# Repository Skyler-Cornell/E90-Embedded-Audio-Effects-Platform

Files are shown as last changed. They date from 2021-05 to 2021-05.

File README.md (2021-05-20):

# E90: Low Cost Embedded DSP Development Platform

The platform is designed for the development of DSP algorithms and provides the hardware and software infrastructure to get started writing programs manipulating real time audio signals in the C programming language. The board manages the analog audio input and output circuits, microcontroller peripherals, and the data flow, allowing a programmer to focus their efforts on designing DSP. The board was also designed wih musicians in mind, and can act as a programmable real time effects unit that players can plug their instruments into and run pre-compiled effects. An eventual goal of the project is to curate a growing library of pre-compiled firmware written by a community of developers that anyone can download and easily upload to the board to try out with their instruments. 

The board supports stereo 24bit audio at 48kHz sampling and implements a highly optimized DMA audio stream scheme. Refer to the Getting Started Manual pdf to ... get started using the platform.

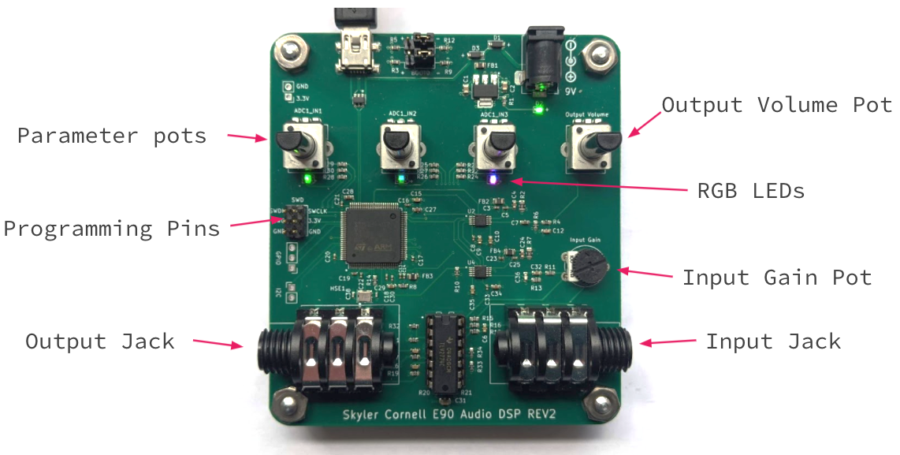
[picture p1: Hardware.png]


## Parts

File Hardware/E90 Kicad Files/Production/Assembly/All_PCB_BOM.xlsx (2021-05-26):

Item # | *Designator | *Qty | Manufacturer | *Mfg Part # | Description / Value | *Package/Footprint | Type | LCSC Part Number
1 | C1,C2,C31 | 3 | Samsung Electro-Mechanics | CL21A106KOQNNNE | 10uF ±10% 16V 0805 Multilayer Ceramic Capacitors | 0805 | SMD | C1713
2 | C12 | 1 | Walsin Tech Corp | 0603B272K101CT | 2.7nF ±10% 100V 0603 Multilayer Ceramic Capacitors | 0603 | SMD | C302023
3 | C13,C17,C19,C21,C22,C16,C18,C20,C3,C8,C33,C23,C30,C5,C25 | 15 | Walsin Tech Corp | 0402X104K160CT | 100nF ±10% 16V 0402 Multilayer Ceramic Capacitors | 0402 | SMD | C301997
4 | C14 | 1 | CCTC | TCC0402X7R103K500AT | 10nF ±10% 50V 0402 Multilayer Ceramic Capacitors | 0402 | SMD | C688874
5 | C15,C6,C11,C26,C9,C10,C35 | 7 | Murata Electronics | GRM188R61A106ME69D | 10uF ±20% 10V 0603 Multilayer Ceramic Capacitors | 0603 | SMD | C90053
6 | C27,C28 | 2 | YAGEO | CC0603KRX5R8BB225 | 2.2uF ±10% 25V 0603 Multilayer Ceramic Capacitors | 0603 | SMD | C309478
7 | C29,C34,C32 | 3 | Samsung Electro-Mechanics | CL10A105KP8NNNC | 1uF ±10% 10V 0603 Multilayer Ceramic Capacitors | 0603 | SMD | C26413
8 | C36 | 1 | YAGEO | CC0603FRNPO9BN181 | 180pF ±1% 50V 0603 Multilayer Ceramic Capacitors | 0603 | SMD | C527047
9 | C38,C39 | 2 | Murata Electronics | GCM1555C1H120JA16D | 12pF ±5% 50V 0402 Multilayer Ceramic Capacitors | 0402 | SMD | C126495
10 | C4,C24 | 2 | Samsung Electro-Mechanics | CL10A475KP8NNNC | 4.7uF ±10% 10V 0603 Multilayer Ceramic Capacitors | 0603 | SMD | C1705
11 | C7 | 1 | Walsin Tech Corp | 0603X335K100CT | 3.3uF ±10% 10V 0603 Multilayer Ceramic Capacitors | 0603 | SMD | C237213
12 | D1,D3 | 2 | AnBon | B5819W | SOD-123 Schottky Diodes | SOD-123 | SMD | C541627
13 | D2 | 1 | TOGIALED | TJ-S1608CY6T5ALC2G-A5 | Green 0603 Light Emitting Diodes (LED) | 0603 | SMD | C440518
14 | D5,D4,D6 | 3 | Everlight Elec | 19-237/R6GHBHC-A01/2T | RGB SMD Light Emitting Diodes (LED) | SMD | SMD | C60105
15 | FB2,FB4 | 2 | Sunlord | GZ2012D601TF | 600Ω @ 100MHz 0805 Ferrite Beads | 0805 | SMD | C1017
16 | FB3,FB1 | 2 | Sunlord | GZ2012D101TF | 100Ω @ 100MHz 0805 Ferrite Beads | 0805 | SMD | C1015
17 | HSE1 | 1 | Seiko Epson | X1E000021037500 | 16MHz ±10ppm 9pF 60Ω SMD-3225_4P SMD Crystal Resonators | SMD-3225_4P | SMD | C89379
18 | R1 | 1 | UNI-ROYAL(Uniroyal Elec) | 0603WAJ0222T5E | 2.2kΩ ±5% 0.1W 0603 Chip Resistor | 0603 | SMD | C25992
19 | R11,R13 | 2 | UNI-ROYAL(Uniroyal Elec) | 0603WAF5101T5E | 5.1kΩ ±1% 0.1W 0603 Chip Resistor | 0603 | SMD | C23186
20 | R14 | 1 | TyoHM | RMC06031001%N | 100Ω ±1% 0.1W 0603 Chip Resistor | 0603 | SMD | C269700
21 | R16,R15,R18,R17,R19,R12,R5,R9,R3,R20,R21,R10,R33,R34,R31,R32,R6 | 17 | UNI-ROYAL(Uniroyal Elec) | 0603WAJ0104T5E | 100kΩ ±5% 0.1W 0603 Chip Resistor | 0603 | SMD | C15458
22 | R2,R7 | 2 | UNI-ROYAL(Uniroyal Elec) | 0805W8J010JT5E | 1Ω ±5% 0.125W 0805 Chip Resistor | 0805 | SMD | C25288
23 | R27,R26,R25,R24,R23,R22,R28,R29,R30 | 9 | UNI-ROYAL(Uniroyal Elec) | 0603WAD1001T5E | 1kΩ ±0.5% 0.1W 0603 Chip Resistor | 0603 | SMD | C51218
24 | R4 | 1 | FH(Guangdong Fenghua Advanced Tech) | RS-03K4700FT | 470Ω ±1% 0.1W 0603 Chip Resistor | 0603 | SMD | C116694
25 | R8 | 1 | FH(Guangdong Fenghua Advanced Tech) | RS-03K47R0FT | 47Ω ±1% 0.1W 0603 Chip Resistor | 0603 | SMD | C140087
26 | U1 | 1 | Advanced Monolithic Systems | AMS1117-3.3 | Fixed 15V 3.3V 1.3V @ 800mA SOT-223 Dropout Regulators(LDO) | SOT-223 | SMD | C6186
27 | U2 | 1 | Cirrus Logic | CS4344-CZZR | TSSOP-10 Digital To Analog Converters (DACs) | TSSOP-10 | SMD | C8952
28 | U4 | 1 | Cirrus Logic | CS5343-CZZR | TSSOP-10 Analog To Digital Converters (ADCs) | TSSOP-10 | SMD | C323607
29 | U5 | 1 | STMicroelectronics | STM32F407VGT6 | LQFP-100 STM32 Microcontroller | LQFP-100_14x14x05P | SMD | C12345
30 | U6 | 1 | STMicroelectronics | USBLC6-2SC6 | DIODES - ESD SOT-23-6 | SOT-23-6 | SMD | C7519

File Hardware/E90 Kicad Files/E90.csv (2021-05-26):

Reference | Quantity | Value | Footprint | Datasheet | LCSC
C1 C2 C31 | 3 | 10uF | Capacitor_SMD:C_0805_2012Metric | ~ | C15850
C12 | 1 | 2.7nF | Capacitor_SMD:C_0603_1608Metric | ~ | C1609
C13 C17 C19 C21 C22 C16 C18 C20 C3 C8 C33 C23 | 12 | 100nf | Capacitor_SMD:C_0402_1005Metric | ~ | C1525
C14 | 1 | 10nF | Capacitor_SMD:C_0402_1005Metric | ~ | C15195
C15 C6 C11 C26 C9 C10 C35 | 7 | 10uF | Capacitor_SMD:C_0603_1608Metric | ~ | C19702
C27 C28 | 2 | 2.2uF | Capacitor_SMD:C_0603_1608Metric | ~ | C23630
C29 C34 C32 | 3 | 1uF | Capacitor_SMD:C_0603_1608Metric | ~ | C15849
C30 C5 C25 | 3 | 100nF | Capacitor_SMD:C_0402_1005Metric | ~ | C1525
C36 | 1 | 180pF | Capacitor_SMD:C_0603_1608Metric | ~ | C18437
C38 C39 | 2 | 12pF | Capacitor_SMD:C_0402_1005Metric | ~ | C1547
C4 C24 | 2 | 4.7uF | Capacitor_SMD:C_0603_1608Metric | ~ | C19666
C7 | 1 | 3.3uF | Capacitor_SMD:C_0603_1608Metric | ~ | C51412
D1 D3 | 2 | B5819W | Diode_SMD:D_SOD-123 | ~ | C8598
D2 | 1 | LED_Green | LED_SMD:LED_0603_1608Metric | ~ | C72043
D5 D4 D6 | 3 | LED_RGBA | LED_SMD:19-237-R6GHBHC-A01-2T | ~ | C60105
FB2 FB4 | 2 | 600 @100 MHz | Inductor_SMD:L_0805_2012Metric | ~ | C1017
FB3 FB1 | 2 | 100 @100 MHz | Inductor_SMD:L_0805_2012Metric | ~ | C1015
HSE1 | 1 | 16MHz | Crystal:Crystal_SMD_3225-4Pin_3.2x2.5mm | ~ | C13738
R1 | 1 | 2k2 | Resistor_SMD:R_0603_1608Metric | ~ | C4190
R11 R13 | 2 | 5.1K | Resistor_SMD:R_0603_1608Metric | ~ | C23186
R14 | 1 | 100 | Resistor_SMD:R_0603_1608Metric | ~ | C22775
R16 R15 R18 R17 R19 R12 R5 R9 R3 R20 R21 R10 R33 R34 R31 R32, R6 | 17 | 10k | Resistor_SMD:R_0603_1608Metric | ~ | C25804
R2 R7 | 2 | 1 | Resistor_SMD:R_0805_2012Metric | ~ | C25271
R27 R26 R25 R24 R23 R22 R28 R29 R30 | 9 | 1k | Resistor_SMD:R_0603_1608Metric | ~ | C21190
R4 | 1 | 470 | Resistor_SMD:R_0603_1608Metric | ~ | C23179
R8 | 1 | 47 | Resistor_SMD:R_0603_1608Metric | ~ | C23182
U1 | 1 | AMS1117-3.3 | Package_TO_SOT_SMD:SOT-223-3_TabPin2 | http://www.advanced-monolithic.com/pdf/ds1117.pdf | C6186
U2 | 1 | CS4344_CZZ | Package_TSSOP_SMD:SOP50P490X110-10N
U4 | 1 | CS5343_CZZ | Package_TSSOP_SMD:SOP50P490X110-10N
U5 | 1 | STM32F407VGT60 | Package_QFP:LQFP-100_14x14mm_P0.5mm | http://www.st.com/st-web-ui/static/active/en/resource/technical/document/datasheet/DM00037051.pdf | C919362
U6 | 1 | USBLC6-2SC6 | Package_TO_SOT_SMD:SOT-23-6 | http://www2.st.com/resource/en/datasheet/CD00050750.pdf | C7519

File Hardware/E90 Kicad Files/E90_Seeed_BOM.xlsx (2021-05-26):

Designator | Qty | Manufacturer Part Number or Seeed SKU | Link | Manufactorer | Footprint | Value
C1 C2 C31 | 3 | 302010158 | https://statics3.seeedstudio.com/fusion/opl/datasheet/302010158.pdf | YAGEO | 0805 | 10uF
C12 | 1 | 0603B272K500NT | https://file.elecfans.com/web1/M00/B0/EC/pIYBAF3vREiAa21yAA-X9Qix-h8261.pdf?filename=0603B272K500NT_FH.pdf | FH | 0603 | 2.7nF
C13 C17 C19 C21 C22 C16 C18 C20 C3 C8 C33 C23 | 12 | 302010024 | https://statics3.seeedstudio.com/fusion/opl/datasheet/302010024.pdf | YAGEO | 0402 | 100nf
C14 | 1 | 302010006 | https://statics3.seeedstudio.com/fusion/opl/datasheet/302010006.pdf | YAGEO | 0402 | 10nF
C15 C6 C11 C26 C9 C10 C35 | 7 | 302010103 | https://statics3.seeedstudio.com/fusion/opl/datasheet/302010103.pdf | YAGEO | 0603 | 10uF
C27 C28 | 2 | 302010054 | https://statics3.seeedstudio.com/fusion/opl/datasheet/302010054.pdf | YAGEO | 0603 | 2.2uF
C29 C34 C32 | 3 | 302010139 | https://statics3.seeedstudio.com/fusion/opl/datasheet/302010139.pdf | YAGEO | 0603 | 1uF
C30 C5 C25 | 3 | 302010024 | https://statics3.seeedstudio.com/fusion/opl/datasheet/302010024.pdf | YAGEO | 0402 | 100nF
C36 | 1 | 0603B181K500NT | https://file.elecfans.com/web1/M00/7D/4D/o4YBAFwKKSOANZPCAA-X9Qix-h8480.pdf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 | FH | 0603 | 180pF
C38 C39 | 2 | 302010049 | https://statics3.seeedstudio.com/fusion/opl/datasheet/302010049.pdf | YAGEO | 0402 | 12pF
C4 C24 | 2 | 302010111 | https://statics3.seeedstudio.com/fusion/opl/datasheet/302010111.pdf | YAGEO | 0603 | 4.7uF
C7 | 1 | CL10A335KP8NNNC | https://file.elecfans.com/web1/M00/5C/4C/o4YBAFt04FWAbe4gAAKwH_HJHDI122.pdf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 | SAMSUNG | 0603 | 3.3uF
R1 | 1 | 301010124 | https://statics3.seeedstudio.com/fusion/opl/datasheet/301010124.pdf | YAGEO | 0603 | 2k2
R11 R13 | 2 | 301010227 | https://statics3.seeedstudio.com/fusion/opl/datasheet/301010227.pdf | YAGEO | 0603 | 5.1K
R14 | 1 | 301010090 | https://statics3.seeedstudio.com/fusion/opl/datasheet/301010090.pdf | YAGEO | 0603 | 100
R16 R15 R18 R17 R19 R12 R5 R9 R3 R20 R21 R10 R33 R34 R31 R32 | 16 | 301010293 | https://statics3.seeedstudio.com/fusion/opl/datasheet/301010293.pdf | YAGEO | 0603 | 10k
R2 R7 | 2 | 0805W8F100KT5E | https://file.elecfans.com/web1/M00/61/0C/o4YBAFt-dwWACUP4AAh1Wgzv73Y460.pdf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 | Uniohm | 0805 | 1
R27 R26 R25 R24 R23 R22 R28 R29 R30 | 9 | 301010291 | https://statics3.seeedstudio.com/fusion/opl/datasheet/301010291.pdf | YAGEO | 0603 | 1k
R4 | 1 | 301010088 | https://statics3.seeedstudio.com/fusion/opl/datasheet/301010088.pdf | YAGEO | 0603 | 470
R6 | 1 | 301010293 | https://statics3.seeedstudio.com/fusion/opl/datasheet/301010293.pdf | YAGEO | 0603 | 10K
R8 | 1 | 301010091 | https://statics3.seeedstudio.com/fusion/opl/datasheet/301010091.pdf | YAGEO | 0603 | 47
U1 | 1 | AMS1117-3.3 | https://file.elecfans.com/web1/M00/B9/0E/pIYBAF57-siAbfa2AAFzrzYJ30Q057.pdf?filename=AMS1117_AMS.pdf | AMS(美国) | SOT-223-3 | AMS1117-3.3
U2 | 1 | CS4344-CZZR | https://d3uzseaevmutz1.cloudfront.net/pubs/proDatasheet/CS4344-45-48_F2.pdf | Cirrus Logic | 10LD TSSOP | CS4344_CZZ
U5 | 1 | STM32F407VGT6 | https://www.mouser.com/datasheet/2/389/dm00037051-1797298.pdf | ST | LQPF-100 | STM32F407VGT60
U6 | 1 | USBLC6-2P6 | https://file.elecfans.com/web1/M00/7F/9E/pIYBAFwjN3uAIFePAANr_4V7kNY752.pdf?filename=USBLC6-2_ST.pdf | ST | SOT-23-6 | USBLC6-2SC6
D1 D3 | 2 | B5819W | https://file.elecfans.com/web1/M00/8A/32/pIYBAFyLiveAInCMAAthN3CVBXo401.pdf?filename=1505718310707869662.pdf | MDD | SOD-123 | B5819W
D2 | 1 | LTST-C193KGKT-5A | https://file.elecfans.com/web1/M00/E7/12/pIYBAGBbCBiAIkcZAAsLyi8is5U283.pdf | Lite-On | 0603 | LED_Green
D5 D4 D6 | 3 | 19-237/R6GHBHC-A01/2T | https://file.elecfans.com/web1/M00/83/04/o4YBAFxJLzGANrbBAANmbS5MZXs171.pdf?filename=19-237-R6GHBHC-A01-2T.pdf | Everlight | LED_SMD:19-237-R6GHBHC-A01-2T | LED_RGBA
FB2 FB4 | 2 | MPZ2012S101AT000 | https://file.elecfans.com/web1/M00/9E/A5/pIYBAF05UT6AJDrFAALHHPpGlro344.pdf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 | TDK | 0805 | 100 @100 MHz
FB3 FB1 | 2 | MPZ2012S101AT000 | https://file.elecfans.com/web1/M00/9E/A5/pIYBAF05UT6AJDrFAALHHPpGlro344.pdf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 | TDK | 0805 | 100 @100 MHz
HSE1 | 1 | X322516MLB4SI | https://file.elecfans.com/web1/M00/9A/01/o4YBAF0dzAaAAvQhABlQ0qxO8IM648.pdf?filename=X3225_YXC.pdf | YXC | Crystal:Crystal_SMD_3225-4Pin_3.2x2.5mm | 16MHz

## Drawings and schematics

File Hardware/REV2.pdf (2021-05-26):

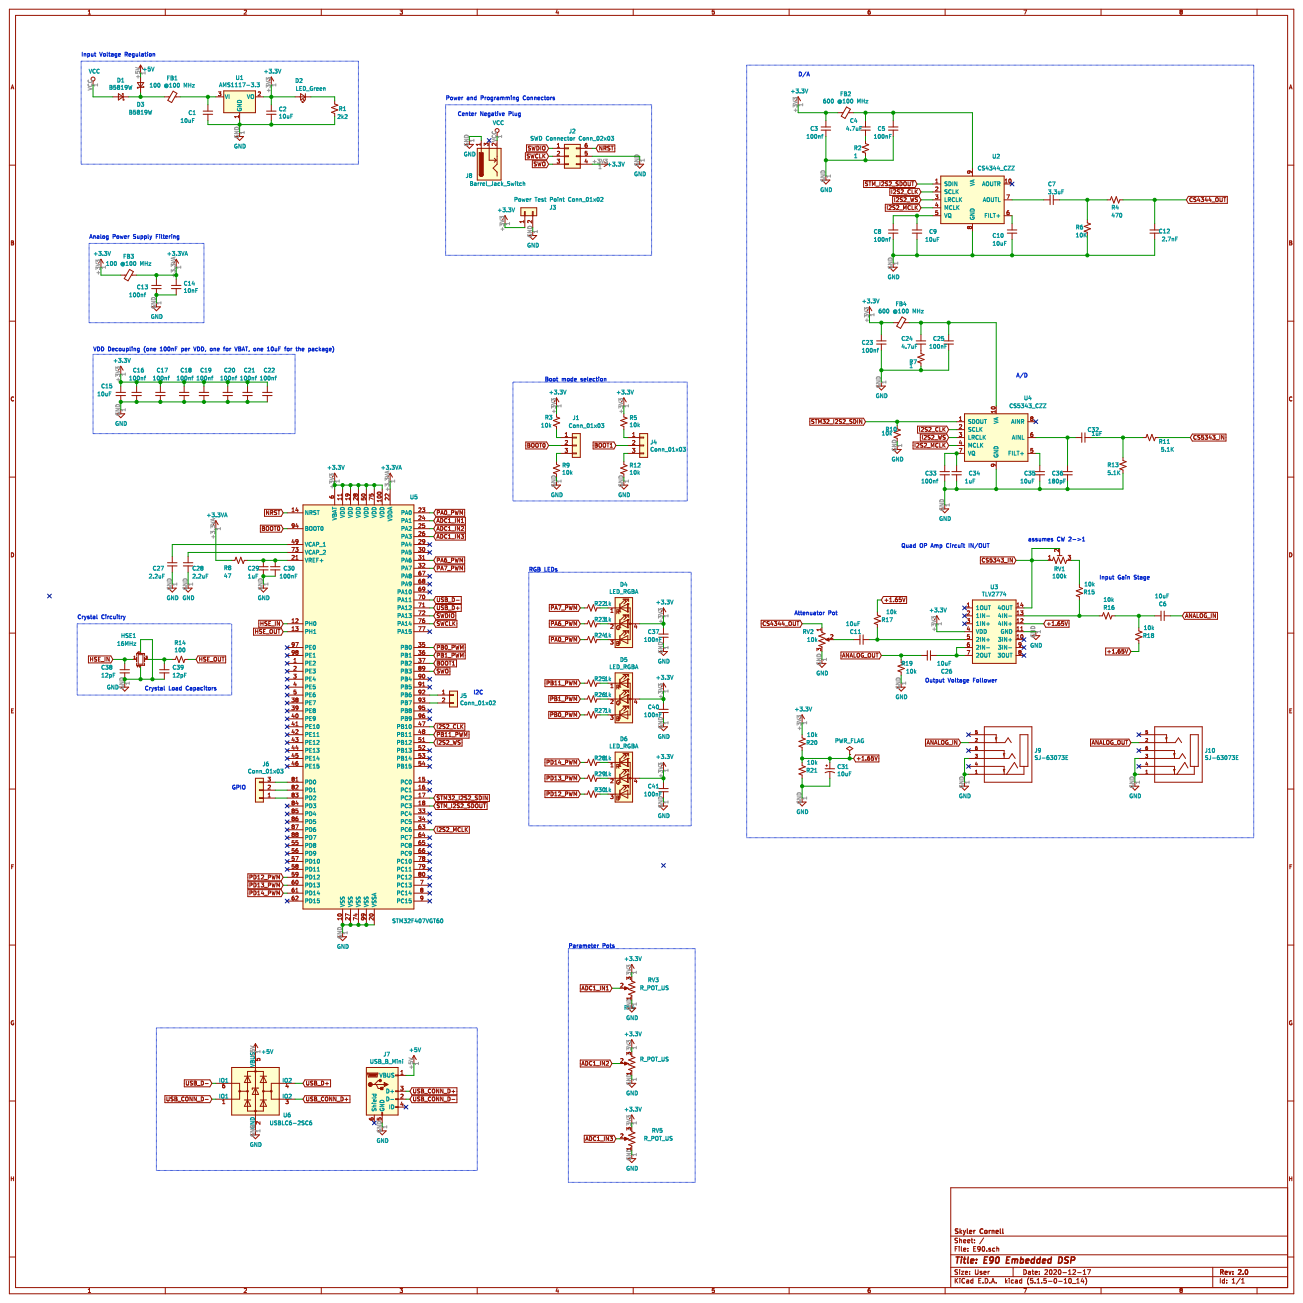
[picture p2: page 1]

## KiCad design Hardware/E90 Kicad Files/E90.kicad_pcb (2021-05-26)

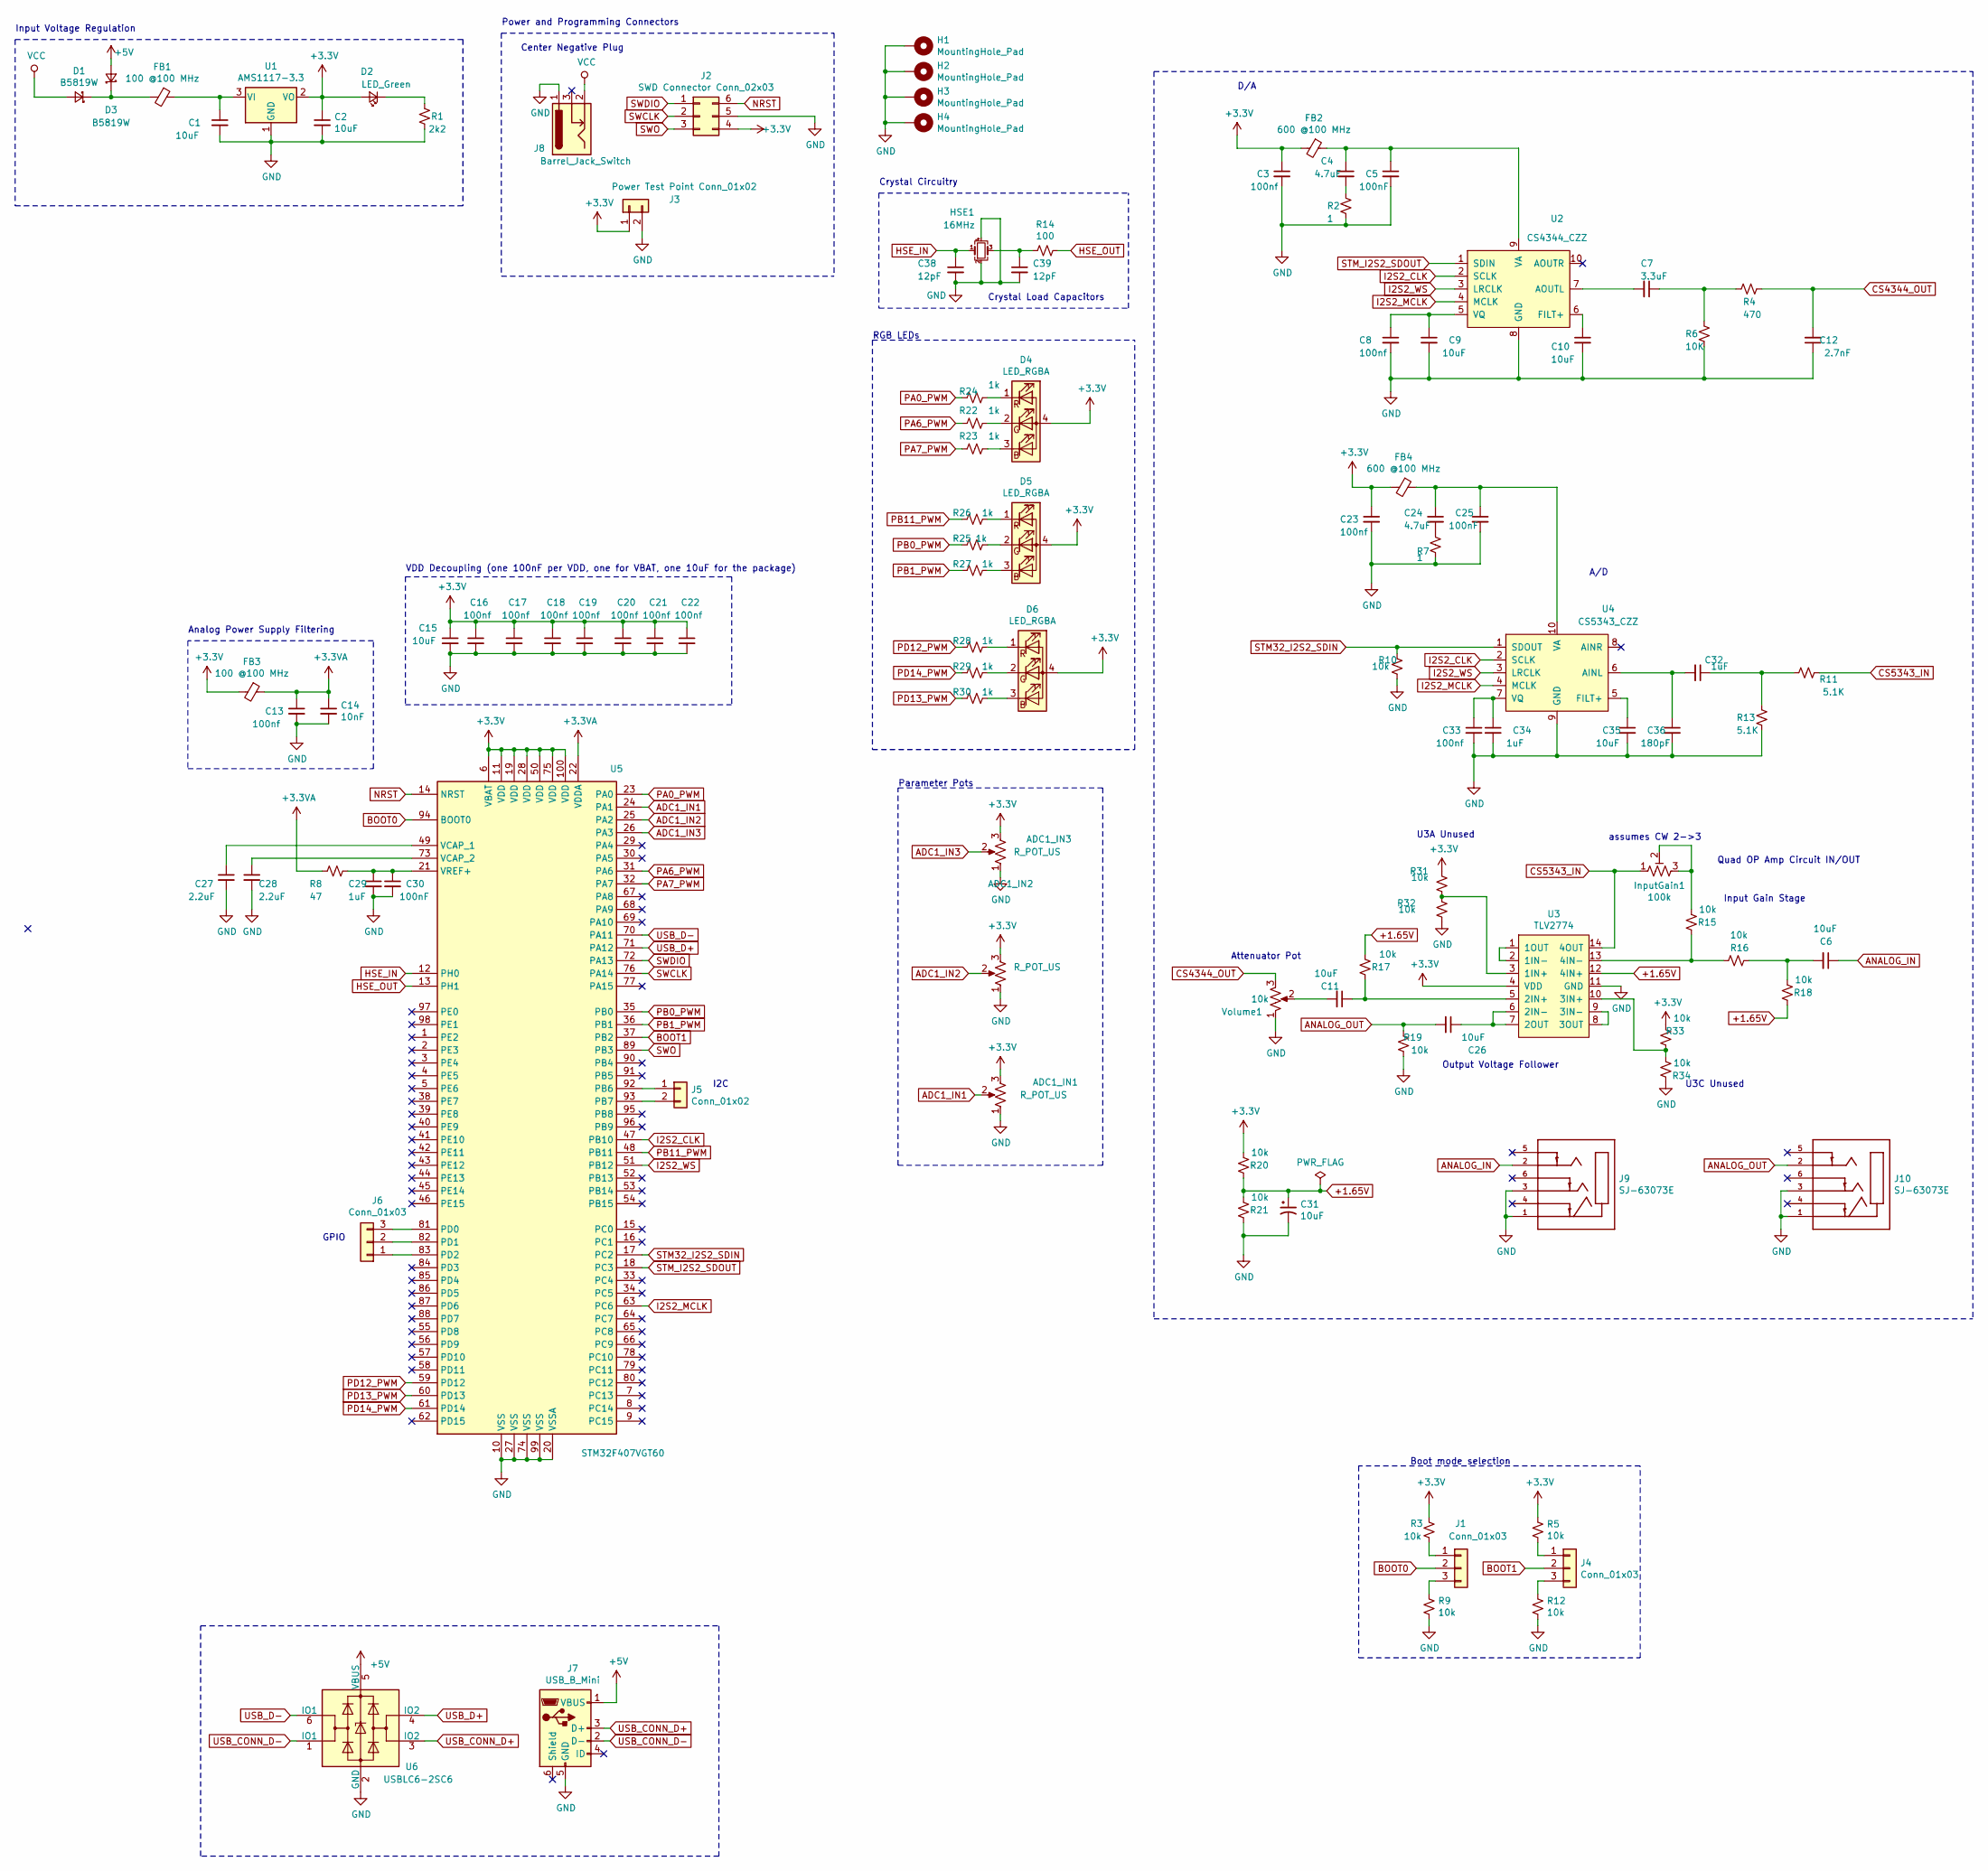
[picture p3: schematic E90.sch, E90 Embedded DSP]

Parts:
ADC1_IN1, ADC1_IN2, ADC1_IN3: R_POT_US; Potentiometer_Bourns_PTV09A-1_Single_Vertical
C1, C2: 10uF; C_0805_2012Metric; LCSC Part # C15850
C3, C8, C13, C16, C17, C18, C19, C20, C21, C22, C23, C33: 100nf; C_0402_1005Metric; LCSC Part # C1525
C4, C24: 4.7uF; C_0603_1608Metric; LCSC Part # C19666
C5, C25, C30: 100nF; C_0402_1005Metric; LCSC Part # C1525
C6, C9, C10, C11, C15, C26, C35: 10uF; C_0603_1608Metric; LCSC Part # C19702
C7: 3.3uF; C_0603_1608Metric; LCSC Part # C51412
C12: 2.7nF; C_0603_1608Metric; LCSC Part # C1609
C14: 10nF; C_0402_1005Metric; LCSC Part # C15195
C27, C28: 2.2uF; C_0603_1608Metric; LCSC Part # C23630
C29, C32, C34: 1uF; C_0603_1608Metric; LCSC Part # C15849
C31: 10uF; C_0805_2012Metric; LCSC C15850
C36: 180pF; C_0603_1608Metric; LCSC Part # C18437
C38, C39: 12pF; C_0402_1005Metric; LCSC Part # C1547
D1, D3: B5819W; D_SOD-123; LCSC Part # C8598
D2: LED_Green; LED_0603_1608Metric; LCSC Part # C72043
D4, D5, D6: LED_RGBA; 19-237-R6GHBHC-A01-2T; LCSC C60105
FB1, FB3: 100 @100 MHz; L_0805_2012Metric; LCSC Part # C1015
FB2, FB4: 600 @100 MHz; L_0805_2012Metric; LCSC Part # C1017
H1, H2, H3, H4: MountingHole_Pad; MountingHole_4.3mm_M4_Pad_Via
HSE1: 16MHz; Crystal_SMD_3225-4Pin_3.2x2.5mm; LCSC Part # C13738
InputGain1: 100k; Potentiometer_Piher_PT-10-V10_Vertical
J1, J4, J6: Conn_01x03; PinHeader_1x03_P2.54mm_Vertical
J2: SWD Connector Conn_02x03; PinHeader_2x03_P2.54mm_Vertical
J3: Power Test Point Conn_01x02; PinHeader_1x02_P2.54mm_Vertical
J5: Conn_01x02; PinHeader_1x02_P2.54mm_Vertical
J7: USB_B_Mini; USB_Mini-B_Lumberg_2486_01_Horizontal
J8: Barrel_Jack_Switch; BarrelJack_Horizontal
J9, J10: SJ-63073E; CUI_SJ-63073E; PARTREV 1.0
R1: 2k2; R_0603_1608Metric; LCSC Part # C4190
R2, R7: 1; R_0805_2012Metric; LCSC Part # C25271
R3, R5, R9, R10, R12: 10k; R_0603_1608Metric; LCSC Part # C25804
R4: 470; R_0603_1608Metric; LCSC Part # C23179
R6: 10K; R_0603_1608Metric; LCSC Part # C25804
R8: 47; R_0603_1608Metric; LCSC Part # C23182
R11, R13: 5.1K; R_0603_1608Metric; LCSC Part # C23186
R14: 100; R_0603_1608Metric; LCSC Part # C22775
R15, R16, R17, R18, R19, R20, R21, R31, R32, R33, R34: 10k; R_0603_1608Metric; LCSC Part # C23186
R22, R23, R24, R25, R26, R27, R28, R29, R30: 1k; R_0603_1608Metric; LCSC Part # C23182
U1: AMS1117-3.3; SOT-223-3_TabPin2; LCSC Part # C6186
U2: CS4344_CZZ; SOP50P490X110-10N
U3: TLV2774; DIP-14_W7.62mm_LongPads
U4: CS5343_CZZ; SOP50P490X110-10N
U5: STM32F407VGT60; LQFP-100_14x14mm_P0.5mm; LCSC Part # C12345
U6: USBLC6-2SC6; SOT-23-6; LCSC C7519
Volume1: 10k; Potentiometer_Bourns_PTV09A-1_Single_Vertical

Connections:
+1.65V: C31.1, R17.1, R18.2, R20.2, R21.1, U3.12 (4IN+)
+3.3VA: C13.1, C14.1, FB3.1, R8.1, U5.22 (VDDA)
+3V3: ADC1_IN1.3, ADC1_IN2.3, ADC1_IN3.3, C2.1, C3.1, C15.1, C16.1, C17.1, C18.1, C19.1, C20.1, C21.1, C22.1, C23.1, D2.2 (A), D4.4 (A), D5.4 (A), D6.4 (A), FB2.2, FB3.2, FB4.2, J2.4, J3.1, R3.2, R5.2, R20.1, R31.1, R33.1, U1.2 (VO), U3.4 (VDD), U5.6 (VBAT), U5.11 (VDD), U5.19 (VDD), U5.28 (VDD), U5.50 (VDD), U5.75 (VDD), U5.100 (VDD); also elsewhere on the board
+5V: D3.2 (A), J7.1 (VBUS), U6.5 (VBUS)
ADC1_IN1: ADC1_IN1.2, U5.24 (PA1)
ADC1_IN2: ADC1_IN2.2, U5.25 (PA2)
ADC1_IN3: ADC1_IN3.2, U5.26 (PA3)
ANALOG_IN: C6.1, J9.2
ANALOG_OUT: C26.2, J10.2, R19.1
BOOT0: J1.2, U5.94 (BOOT0)
BOOT1: J4.2, U5.37 (PB2)
CS4344_OUT: C12.2, R4.2, Volume1.3; also elsewhere on the board
CS5343_IN: InputGain1.1, R11.1, U3.14 (4OUT)
GND: ADC1_IN1.1, ADC1_IN2.1, ADC1_IN3.1, C1.2, C2.2, C3.2, C5.2, C8.2, C9.2, C10.2, C12.1, C13.2, C14.2, C15.2, C16.2, C17.2, C18.2, C19.2, C20.2, C21.2, C22.2, C23.2, C25.2, C27.2, C28.2, C29.2, C30.2, C31.2, C33.2, C34.2, C35.2, C36.2, C38.2, C39.2, H1.1, H2.1, H3.1, H4.1, HSE1.2, HSE1.4, J2.5, J3.2, J7.5 (GND), J8.1, J9.1, J9.3, J10.1, J10.3, R1.2, R2.1, R6.1, R7.1, R9.1, R10.1, R12.1, R13.1, R19.2, R21.2, R32.2, R34.2, U1.1 (GND), U2.8 (GND), U3.11 (GND), U4.9 (GND), U5.10 (VSS), U5.20 (VSSA), U5.27 (VSS), U5.74 (VSS), U5.99 (VSS), U6.2 (GND), Volume1.1; also elsewhere on the board
HSE_IN: C38.1, HSE1.1, U5.12 (PH0)
HSE_OUT: R14.2, U5.13 (PH1)
I2S2_CLK: U2.2 (SCLK), U4.2 (SCLK), U5.47 (PB10)
I2S2_MCLK: U2.4 (MCLK), U4.4 (MCLK), U5.63 (PC6)
I2S2_WS: U2.3 (LRCLK), U4.3 (LRCLK), U5.51 (PB12)
NRST: J2.6, U5.14 (NRST); also elsewhere on the board
unnamed: C1.1, FB1.1, U1.3 (VI)
unnamed: C4.1, C5.1, FB2.1, U2.9 (VA)
unnamed: C4.2, R2.2
unnamed: C6.2, R16.2, R18.1
unnamed: C7.1, R4.1, R6.2
unnamed: C7.2, U2.7 (AOUTL)
unnamed: C8.1, C9.1, U2.5 (VQ)
unnamed: C10.1, U2.6 (FILT+)
unnamed: C11.1, R17.2, U3.5 (2IN+)
unnamed 29: C11.2, Volume1.2; also elsewhere on the board
unnamed: C24.1, C25.1, FB4.1, U4.10 (VA)
unnamed: C24.2, R7.2
unnamed: C26.1, U3.6 (2IN-), U3.7 (2OUT)
unnamed: C27.1, U5.49 (VCAP_1)
unnamed: C28.1, U5.73 (VCAP_2)
unnamed: C29.1, C30.1, R8.2, U5.21 (VREF+)
unnamed: C32.1, R11.2, R13.2
unnamed: C32.2, C36.1, U4.6 (AINL)
unnamed: C33.1, C34.1, U4.7 (VQ)
unnamed: C35.1, U4.5 (FILT+)
unnamed: C39.1, HSE1.3, R14.1
unnamed: D1.1 (K), D3.1 (K), FB1.2
unnamed 42: D2.1 (K), R1.1; also elsewhere on the board
unnamed: D4.1 (RK), R24.2
unnamed: D4.2 (GK), R22.2
unnamed: D4.3 (BK), R23.2
unnamed: D5.1 (RK), R26.2
unnamed: D5.2 (GK), R25.2
unnamed: D5.3 (BK), R27.2
unnamed: D6.1 (RK), R28.2
unnamed: D6.2 (GK), R29.2
unnamed: D6.3 (BK), R30.2
unnamed: InputGain1.2, InputGain1.3, R15.1
unnamed: J1.1, R3.1
unnamed: J1.3, R9.2
unnamed: J4.1, R5.1
unnamed: J4.3, R12.2
unnamed: J5.1, U5.92 (PB6)
unnamed: J5.2, U5.93 (PB7)
unnamed: J6.1, U5.83 (PD2)
unnamed: J6.2, U5.82 (PD1)
unnamed: J6.3, U5.81 (PD0)
unnamed: R15.2, R16.1, U3.13 (4IN-)
unnamed: R31.2, R32.1, U3.3 (1IN+)
unnamed: R33.2, R34.1, U3.10 (3IN+)
unnamed: U3.1 (1OUT), U3.2 (1IN-)
unnamed: U3.8 (3OUT), U3.9 (3IN-)
PA0_PWM: R24.1, U5.23 (PA0)
PA6_PWM: R22.1, U5.31 (PA6)
PA7_PWM: R23.1, U5.32 (PA7)
PB0_PWM: R25.1, U5.35 (PB0)
PB1_PWM: R27.1, U5.36 (PB1)
PB11_PWM: R26.1, U5.48 (PB11)
PD12_PWM: R28.1, U5.59 (PD12)
PD13_PWM: R30.1, U5.60 (PD13)
PD14_PWM: R29.1, U5.61 (PD14)
STM32_I2S2_SDIN: R10.2, U4.1 (SDOUT), U5.17 (PC2)
STM_I2S2_SDOUT: U2.1 (SDIN), U5.18 (PC3)
SWCLK: J2.2, U5.76 (PA14); also elsewhere on the board
SWDIO: J2.1, U5.72 (PA13); also elsewhere on the board
SWO: J2.3, U5.89 (PB3); also elsewhere on the board
USB_CONN_D+: J7.3 (D+), U6.3 (IO2)
USB_CONN_D-: J7.2 (D-), U6.1 (IO1)
USB_D+: U5.71 (PA12), U6.4 (IO2)
USB_D-: U5.70 (PA11), U6.6 (IO1)
VCC: D1.2 (A), J8.2

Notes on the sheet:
Power and Programming Connectors
Crystal Circuitry
D/A
Analog Power Supply Filtering
Crystal Load Capacitors
VDD Decoupling (one 100nF per VDD, one for VBAT, one 10uF for the package)
assumes CW 2->3
Attenuator Pot
Boot mode selection
Output Voltage Follower
Input Gain Stage
Parameter Pots
Quad OP Amp Circuit IN/OUT
RGB LEDs
Input Voltage Regulation
A/D
GPIO
I2C
Center Negative Plug
U3C Unused
U3A Unused

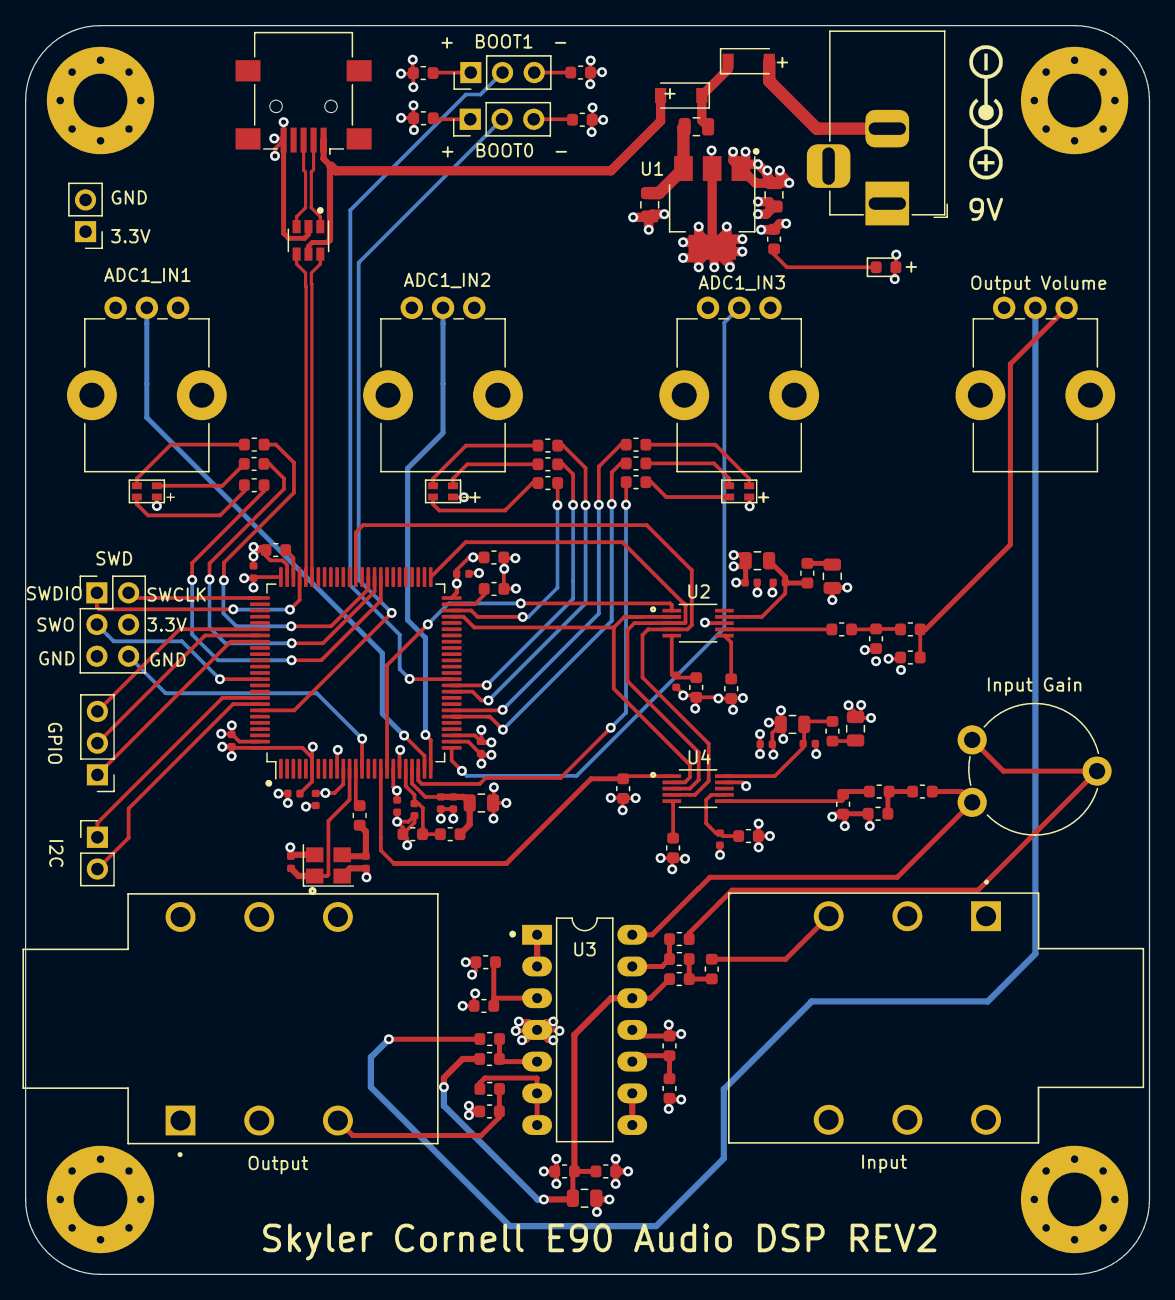
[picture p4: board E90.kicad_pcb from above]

Board: 4 copper layers, 90.0 x 100.0 mm, 108 parts (0 on the bottom side), 86 nets.

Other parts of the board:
Output Volume: 10k; Potentiometer_Bourns_PTV09A-1_Single_Vertical
Power On: LED_Green; LED_0603_1608Metric
SWD: SWD Connector Conn_02x03; PinHeader_2x03_P2.54mm_Vertical

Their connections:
+3V3: Power On.2, SWD.4; also elsewhere on the board
CS4344_OUT: Output Volume.3; also elsewhere on the board
GND: Output Volume.1, SWD.5; also elsewhere on the board
NRST: SWD.6; also elsewhere on the board
unnamed 29: Output Volume.2; also elsewhere on the board
unnamed 42: Power On.1; also elsewhere on the board
SWCLK: SWD.2; also elsewhere on the board
SWDIO: SWD.1; also elsewhere on the board
SWO: SWD.3; also elsewhere on the board

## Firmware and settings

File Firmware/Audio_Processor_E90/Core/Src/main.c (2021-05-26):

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

/* Includes ------------------------------------------------------------------*/
#include "main.h"

/* USER CODE BEGIN Includes */
#include "audio_process.h"

/* USER CODE END Includes */

ADC_HandleTypeDef hadc1;
DMA_HandleTypeDef hdma_adc1;

I2C_HandleTypeDef hi2c1;

I2S_HandleTypeDef hi2s2;
DMA_HandleTypeDef hdma_i2s2_ext_rx;
DMA_HandleTypeDef hdma_spi2_tx;

TIM_HandleTypeDef htim2;
TIM_HandleTypeDef htim3;
TIM_HandleTypeDef htim4;

PCD_HandleTypeDef hpcd_USB_OTG_FS;

/* USER CODE BEGIN PV */


// global double buffer arrays
uint16_t rx_buf[4];
uint16_t tx_buf[4];
// samples for processing
int in_sample, out_sample;

//ADC pot values
uint32_t adc_buf[3], POT_1, POT_2, POT_3;

/* USER CODE END PV */

void SystemClock_Config(void);
static void MX_GPIO_Init(void);
static void MX_DMA_Init(void);
static void MX_ADC1_Init(void);
static void MX_I2C1_Init(void);
static void MX_I2S2_Init(void);
static void MX_TIM2_Init(void);
static void MX_TIM3_Init(void);
static void MX_TIM4_Init(void);
static void MX_USB_OTG_FS_PCD_Init(void);
/**
  * @brief  The application entry point.
  * @retval int
  */
int main(void)
{
  /* MCU Configuration--------------------------------------------------------*/

  /* Reset of all peripherals, Initializes the Flash interface and the Systick. */
  HAL_Init();

  /* Configure the system clock */
  SystemClock_Config();

  /* Initialize all configured peripherals */
  MX_GPIO_Init();
  MX_DMA_Init();
  MX_ADC1_Init();
  MX_I2C1_Init();
  MX_I2S2_Init();
  MX_TIM2_Init();
  MX_TIM3_Init();
  MX_TIM4_Init();
  MX_USB_OTG_FS_PCD_Init();
  /* USER CODE BEGIN 2 */

  //AUDIO process initializations
  process_init();

  HAL_ADC_Start_DMA(&hadc1, adc_buf, 3); //Start ADC1 and DMA transfers for Pot values
  HAL_I2SEx_TransmitReceive_DMA(&hi2s2, tx_buf, rx_buf, 2); //Start audio double buffer DMA transfers

  /* USER CODE END 2 */

  /* Infinite loop */
  /* USER CODE BEGIN WHILE */
  while (1)
  {
    /* USER CODE END WHILE */

    loop(); //DEFINED IN audio_process.c

    /* USER CODE BEGIN 3 */
  }
  /* USER CODE END 3 */
}

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
/* USER CODE BEGIN 4 */

void HAL_ADC_ConvCpltCallback(ADC_HandleTypeDef* hadc) {

  //compensate for incorrect pot orientation
  POT_1 = 255 - adc_buf[0];
  POT_2 = 255 - adc_buf[1];
  POT_3 = 255 - adc_buf[2];

}

//I2S RX line DMA transfer half complete callback
void HAL_I2SEx_TxRxHalfCpltCallback(I2S_HandleTypeDef *hi2s)
{
  //retrieve sample from rx_buf
  in_sample  = (((int)rx_buf[0]<<16)|rx_buf[1])>>8;

  // do audio processing
  process(&in_sample, &out_sample);

  //place processed sample into tx_buf
  tx_buf[0] = (out_sample>>8) & 0xFFFF;
  tx_buf[1] = out_sample & 0xFFFF;

}

//I2S RX line DMA transfer complete callback
void HAL_I2SEx_TxRxCpltCallback(I2S_HandleTypeDef *hi2s)
{
  //retrieve sample from rx_buf
  in_sample  = (((int)rx_buf[2]<<16)|rx_buf[3])>>8;

  // does audio processing
  process(&in_sample, &out_sample);

  //place processed sample into tx_buf
  tx_buf[2] = (out_sample>>8) & 0xFFFF;
  tx_buf[3] = out_sample & 0xFFFF;

}

/* USER CODE END 4 */
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


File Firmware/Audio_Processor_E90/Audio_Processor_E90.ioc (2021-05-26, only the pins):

Mcu.UserName=STM32F407VGTx
PA0-WKUP.Signal=S_TIM2_CH1_ETR
PA1.Signal=ADCx_IN1
PA11.Signal=USB_OTG_FS_DM
PA12.Signal=USB_OTG_FS_DP
PA13.Signal=SYS_JTMS-SWDIO
PA14.Signal=SYS_JTCK-SWCLK
PA2.Signal=ADCx_IN2
PA3.Signal=ADCx_IN3
PA6.Signal=S_TIM3_CH1
PA7.Signal=S_TIM3_CH2
PB0.Signal=S_TIM3_CH3
PB1.Signal=S_TIM3_CH4
PB10.Signal=I2S2_CK
PB11.Signal=S_TIM2_CH4
PB12.Signal=I2S2_WS
PB3.Signal=SYS_JTDO-SWO
PB6.Signal=I2C1_SCL
PB7.Signal=I2C1_SDA
PC2.Signal=I2S2_ext_SD
PC3.Signal=I2S2_SD
PC6.Signal=I2S2_MCK
PD0.Signal=GPIO_Output
PD1.Signal=GPIO_Output
PD12.Signal=S_TIM4_CH1
PD13.Signal=S_TIM4_CH2
PD14.Signal=S_TIM4_CH3
PD2.Signal=GPIO_Output
PE10.Signal=GPIO_Output
PE11.Signal=GPIO_Output
PE8.Signal=GPIO_Input
PE9.Signal=GPIO_Input
PH0-OSC_IN.Signal=RCC_OSC_IN
PH1-OSC_OUT.Signal=RCC_OSC_OUT

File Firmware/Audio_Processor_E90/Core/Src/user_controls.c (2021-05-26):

/*
 * user_controls.c
 *
 *  Created on: May 20, 2021
 *      Author: skylercornell
 */


#include "user_controls.h"

extern TIM_HandleTypeDef htim2;
extern TIM_HandleTypeDef htim3;
extern TIM_HandleTypeDef htim4;

RGB_LED_t LED1;
RGB_LED_t LED2;
RGB_LED_t LED3;



void update_LED(RGB_LED_t *led, uint8_t R, uint8_t G, uint8_t B) {

  *(led->R_CCR) = 255-R;
  *(led->G_CCR) = 255-G;
  *(led->B_CCR) = 255-B;

}

/*
 * Assign Timers and channels to each LED Struct and start the pWM
 *
 */
void init_LEDs() {

  /*
   * Assign RGB_LED_t struct fields to the timer handles and PWM capture
   * compare register addresses corresponding to the connection
   * of the 3 onboard LEDs
   * It's possible ythe R_TIM,G_TIM,B_TIM fields serve no purpose. Because once
   * the TIM PWM is running after Starting them, just need to update the capture
   * compare registers, which can be done by dereferencing the R_CCR field and
   * changing its contents, to change the color.
   */

  //LED 1
  LED1.R_CCR = &(htim4.Instance->CCR1);
  LED1.G_CCR = &(htim4.Instance->CCR3);
  LED1.B_CCR = &(htim4.Instance->CCR2);

  //LED 2
  LED2.R_CCR = &(htim2.Instance->CCR4);
  LED2.G_CCR = &(htim3.Instance->CCR3);
  LED2.B_CCR = &(htim3.Instance->CCR4);

  //LED 3
  LED3.R_CCR = &(htim2.Instance->CCR1);
  LED3.G_CCR = &(htim3.Instance->CCR1);
  LED3.B_CCR = &(htim3.Instance->CCR2);

  update_LED(&LED1, 0,0,0);
  update_LED(&LED2, 0,0,0);
  update_LED(&LED3, 0,0,0);

  //LED 1
  HAL_TIM_PWM_Start(&htim4,TIM_CHANNEL_1);
  HAL_TIM_PWM_Start(&htim4,TIM_CHANNEL_3);
  HAL_TIM_PWM_Start(&htim4,TIM_CHANNEL_2);

  //LED 2
  HAL_TIM_PWM_Start(&htim2,TIM_CHANNEL_4);
  HAL_TIM_PWM_Start(&htim3,TIM_CHANNEL_3);
  HAL_TIM_PWM_Start(&htim3,TIM_CHANNEL_4);

  //LED 3
  HAL_TIM_PWM_Start(&htim2,TIM_CHANNEL_1);
  HAL_TIM_PWM_Start(&htim3,TIM_CHANNEL_1);
  HAL_TIM_PWM_Start(&htim3,TIM_CHANNEL_2);


}

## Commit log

2020-12-30 imported custom symbol libs from old directory all E90 project files can live in this directory
    [E90.kicad_pcb, E90.sch]
2020-12-30 update untracked
    [E90.kicad_pcb, E90.sch]
2020-12-30 refactoring PCB
    [E90.kicad_pcb, E90.sch]
2020-12-31 finished pcb 1.0
    [E90.kicad_pcb, E90.sch]
2020-12-31 added ground pours on all 4 layers
    [E90.kicad_pcb]
2021-01-01 added pdf
    [E90-BOM.csv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]
2021-01-02 Gerbers finalized for Rev1 znd sent to JLCPCB for fabrication
    [E90-BOM.csv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]
2021-01-18 Ping Pong Buf working on custom board. have not tested passthrough yet
2021-01-22 revisions to audio framework
2021-03-28 started Pcb rev2
    [E90.sch]
2021-04-05 Finished rev2 schem, now onto the PCB
    [E90.sch]
2021-04-07 PCB priog
    [E90.kicad_pcb, E90.sch]
2021-04-08 finished pcb
    [E90.kicad_pcb, E90.sch]
2021-04-12 added PCB image
    [All_PCB_BOM.xlsx, E90-BOM.csv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]
2021-04-12 added PCB image to readme
2021-04-12 PCB image rename
2021-05-22 finished LED API for now
2021-05-26 LED and POT API working

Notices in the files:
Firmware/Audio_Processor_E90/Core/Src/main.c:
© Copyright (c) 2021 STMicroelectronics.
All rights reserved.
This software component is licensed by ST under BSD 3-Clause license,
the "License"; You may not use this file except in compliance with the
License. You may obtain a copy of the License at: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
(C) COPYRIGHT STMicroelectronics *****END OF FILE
